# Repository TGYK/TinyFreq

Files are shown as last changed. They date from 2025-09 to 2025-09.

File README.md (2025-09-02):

# TinyFreq
An ATTiny85-based frequency multiplier for use in 1984-1985 Pontiac Fieros for digital cruise control conversion. May be applicable in other use cases. The PCB is designed to be plugged into the harness at C246 where the old cruise control servo control module plugged in, and jumpers relevant stalk signals to back of vehicle via old servo control wires. See table below for details.
|Function|Vacuum Cruise Connector|
|-:|:-|
|Set/Coast|A|
|Multiplied VSS|B|
|GND|C|
|Resume/Acc|D|
|Cruise Enable|E|

## Bill of Materials

|Reference|Device|Value|
|---:|:----:|:----|
|R1|Resistor|100Ω|
|R2|Resistor|10kΩ|
|R3|Resistor|10kΩ|
|R4|Resistor|10kΩ|
|C1|Capacitor|N/A|
|C2|Capacitor|0.33㎌|
|C3|Capacitor|0.1u㎌|
|D1|Diode|1N4001|
|D2|TVS Diode|SA16A|
|D3|TVS Diode|SA30A|
|D4|TVS Diode|SA30A|
|Q1|N-Channel Enhancement FET|2N7000|
|Q2|N-Channel Enhancement FET|2N7000|
|U1|Linear Voltage Regulator|L78L05|
|U2|Microcontroller|ATTiny85|
|J2|Pin Header|2x3, 2.54mm|

## Uploading
### Using an Arduino Uno/Mega as a a programmer.
**THESE STEPS ARE CURRENTLY UNTESTED - FOLLOW AT YOUR OWN RISK**
1. [Setup your Arduino as a programmer and wire to the ISP connection](https://docs.arduino.cc/built-in-examples/arduino-isp/ArduinoISP/), but do not attempt to burn a bootloader to the target.
2. Open the PlatformIO project in VSCode and verify the project builds by clicking the checkmark on the toolbar at the bottom left of the window.
3. Modify the line ```upload_port = SERIAL_PORT_HERE``` within platformio.ini to reflect the serial port that your arduino-as-programmer is connected to, and save the file.
4. If using an arduino mega, modify the line ```${platformio.packages_dir}/tool-avrdude/avrdude.conf``` within platformio.ini to be ```${platformio.packages_dir}/tool-avrdude-megaavr/avrdude.conf``` and save the file.
4. Select the "program_via_ArduinoISP" environment on the bottom toolbar
5. Click the "Upload" arrow on the bottom toolbar

# THIS PROJECT WAS PROUDLY MADE WITHOUT THE USE OF "AI" OR LLM CHATBOTS.

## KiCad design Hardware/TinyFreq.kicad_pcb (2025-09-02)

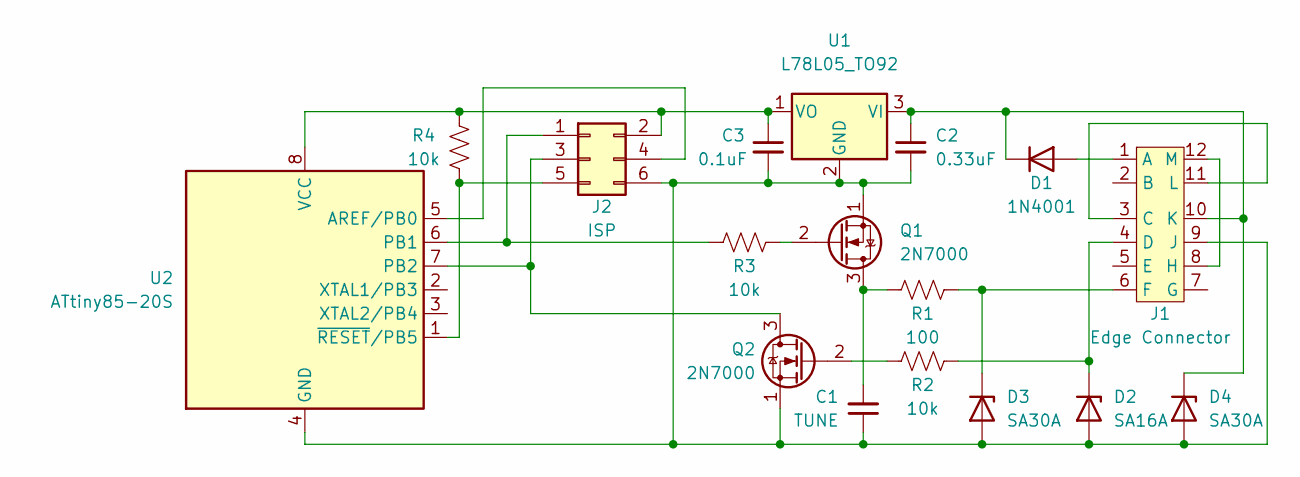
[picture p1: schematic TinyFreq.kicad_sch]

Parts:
C1: TUNE; C_Axial_L3.8mm_D2.6mm_P7.50mm_Horizontal
C2: 0.33uF; C_Axial_L3.8mm_D2.6mm_P7.50mm_Horizontal
C3: 0.1uF; C_Axial_L3.8mm_D2.6mm_P7.50mm_Horizontal
D1: 1N4001; D_DO-41_SOD81_P10.16mm_Horizontal
D2: SA16A; D_A-405_P7.62mm_Horizontal
D3, D4: SA30A; D_A-405_P7.62mm_Horizontal
J1: Edge Connector; CRUISE_EDGE
J2: ISP; PinHeader_2x03_P2.54mm_Vertical
Q1, Q2: 2N7000; TO-92_Inline
R1: 100; R_Axial_DIN0204_L3.6mm_D1.6mm_P5.08mm_Horizontal
R2, R3, R4: 10k; R_Axial_DIN0204_L3.6mm_D1.6mm_P5.08mm_Horizontal
U1: L78L05_TO92; TO-92_Inline
U2: ATtiny85-20S; DIP-8_W7.62mm

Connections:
unnamed: C1.1, C2.2, C3.2, D2.2 (A), D3.2 (A), D4.2 (A), J1.9 (J), J2.6, Q1.1 (S), Q2.1 (S), U1.2 (GND), U2.4 (GND)
unnamed: C1.2, Q1.3 (D), R1.1
unnamed: C2.1, D1.1 (K), D4.1 (K), J1.10 (K), U1.3 (VI)
unnamed: C3.1, J2.2, R4.2, U1.1 (VO), U2.8 (VCC)
unnamed: D1.2 (A), J1.1 (A)
unnamed: D2.1 (K), J1.4 (D), R2.2
unnamed: D3.1 (K), J1.6 (F), R1.2
unnamed: J1.3 (C), J1.11 (L)
unnamed: J1.8 (H), J1.12 (M)
unnamed: J2.1, R3.2, U2.6 (PB1)
unnamed: J2.3, Q2.3 (D), U2.7 (PB2)
unnamed: J2.4, U2.5 (AREF/PB0)
unnamed: J2.5, R4.1, U2.1 (~RESET/PB5)
unnamed: Q1.2 (G), R3.1
unnamed: Q2.2 (G), R2.1

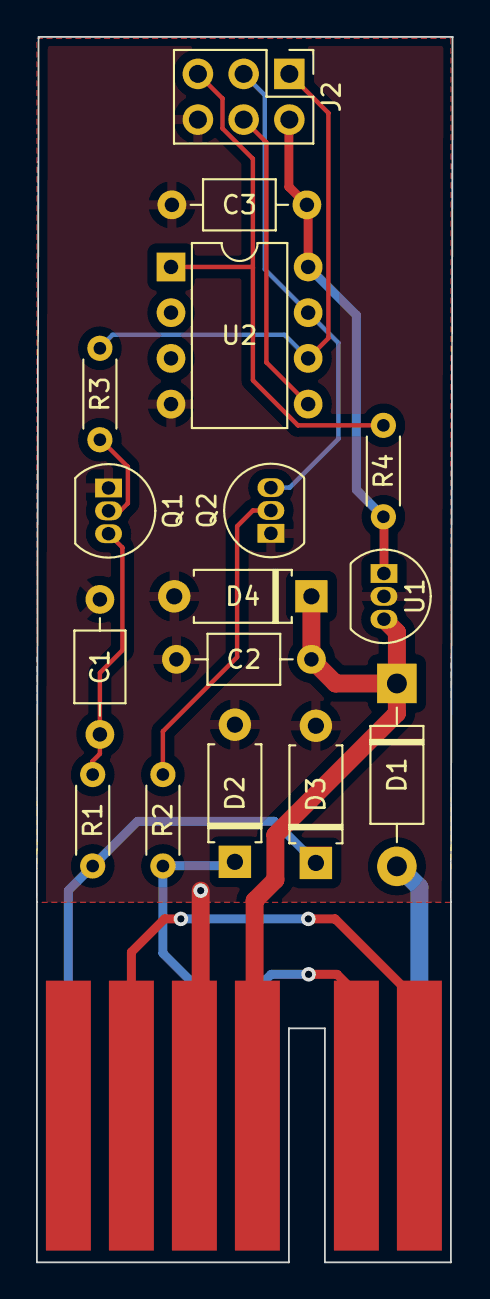
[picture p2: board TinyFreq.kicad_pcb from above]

Board: 2 copper layers, 23.1 x 68.1 mm, 17 parts (0 on the bottom side), 15 nets.

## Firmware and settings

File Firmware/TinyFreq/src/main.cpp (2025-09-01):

#include <Arduino.h>

#define T1_RST TCNT1 &= 0x00
#define T1_STP TCCR1 &= ~((1<<CS10) | (1<<CS11) | (1<<CS12) | (1<<CS13))
#define T1_STA TCCR1 |= ((1<<CS10) | (1<<CS13))
#define T0_RST TCNT0 &= 0x00
#define T0_STP TCCR0B &= ~((1<<CS00) | (1<<CS01) | (1<<CS02))
#define T0_STA TCCR0B |= (1<<CS02)
#define INT0_DS GIMSK &= ~(1<<INT0)
#define INT0_EN GIMSK |= (1<<INT0)

#define FREQ_MULT 2

volatile bool OVF_OCCURRED = true;

ISR(INT0_vect){ //Rising input edge detected
  //Service timer 1 and watchdog, get timer 1 running again ASAP
  T1_STP; //Stop T1 counter
  asm("WDR"); //Reset watchdog timer
  volatile uint8_t togglePW = TCNT1 / (FREQ_MULT * 2); //Read T1 counter, calculate new half PW.. Calculation step may need to be seperate if it takes too long 
  T1_RST; //Reset T1 counter
  T1_STA; //Restart T1 counter

  //OVF flag check - Make sure to measure a full rise-to-rise pulse and not the remainder following a T1 overflow, or a half-pulse during startup.
  if(OVF_OCCURRED){ //If starting up or T1 overflow happened, discard current count/sync
    OVF_OCCURRED = false; //Reset flag
    return; //End interrupt
  }

  //Edge-case - If timer is close to compare match, or is past the new compare match value, trigger an early compare match to toggle output and start a new pulse
  if(TCNT0 > (togglePW - 5)){ //If currently-running putput timer is close to new qpw val or above it, toggle pulse early/sync
    T0_RST; //Reset output timer
    TCCR0B |= (1<<FOC0A); //Force toggle. Bit self-resets? Datasheet ambiguous - FOC0A is a "Strobe bit"
  }

  //Set new compare match for output timer
  OCR0B = togglePW; //Set new half-pulsewidth
  T0_STA; //Start output timer if not already running
  return; //End interrupt
}

ISR(TIM1_OVF_vect){ //Input pulse length overflow
  INT0_DS; //Disable input interrupt
  asm("WDR"); //Reset watchdog timer
  T0_STP; //Stop output timer
  OVF_OCCURRED = true; //Set OVF flag
  T0_RST; //Reset output timer
  PORTB &= ~(1<<PORTB1); //Set output low
  INT0_EN; //Enable input interrupt
  return; //End interrupt
}

void setup() {
  cli(); //Disable global interrupts during setup
  
  //Setup clock
  CLKPR = (CLKPR | (1<<CLKPCE)) & ~((1<<CLKPS3) | (1<<CLKPS2) | (1<<CLKPS1) | (1<<CLKPS0)); //Enable prescaler change
  CLKPR = (CLKPR | (1<<CLKPS3)) & ~(1<<CLKPCE); // clock prescaler = /256
  
  //Setup watchdog 
  WDTCR |= ((1<<WDCE) | (1<<WDE) | (1<<WDP3) | (1<<WDP0)); //Enable watchdog, 8s timeout

  //Setup timers
  TCCR0A |= ((1<<COM0B0) | (1<<WGM01)); //Toggle OC0B0 on match, CTC/mode2
  TIMSK |= (1<<TOIE1); //Overflow int enable on Timer 1

  //Setup DDRB/PORTB
  DDRB = (DDRB | (1<<DDB1)) & ~((1<<DDB0) | (1<<DDB2) | (1<<DDB3) | (1<<DDB4) | (1<<DDB5)); //Unused pins PB0,PB3-5 input for pull-up/high state per datasheet, PB2 input for int0, PB1 output for OC0B0
  PORTB = (PORTB | (1<<PORTB0) | (1<<PORTB2) | (1<<PORTB3) | (1<<PORTB4) | (1<<PORTB5)) & ~(1<<PORTB1); //Pull-up enable, PB1 low

  //Setup interrupts
  MCUCR |= (1<<ISC00) | (1<<ISC01); //INT0 on rising edge
  INT0_EN; //Enable INT0 

  //Setup sleep mode
  MCUCR &= ~((1<<SM0) | (1<<SM1)); //Idle mode
  MCUCR |= (1<<SE); //Enable sleep

  //Setup power-reduction
  ACSR |= (1<<ACD); //Disable analog comparator
  ADCSRA &= ~(1<<ADEN); //Disable ADC
  PRR |= ((1<<PRUSI) | (1<<PRADC)); //Disable USI and ADC clocks

  sei(); //Enable global interrupts
}

void loop() {
  asm("SLEEP"); //Enter idle sleep/wait for interrupt - May be detrimental due to wakeup time (4 cycles + SUT fuse setting)
}

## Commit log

2025-08-31 Initial commit - Schematics, PCB, Code
    [TinyFreq.kicad_pcb, TinyFreq.kicad_sch]
2025-09-01 Interrupt cleanup and operation prioritization, clearer commentson logic.
2025-09-01 Update schematic datasheets and symbols for TVS diodes, update PCB footprints to reflect the pin change.
    [TinyFreq.kicad_pcb, TinyFreq.kicad_sch]
2025-09-01 Generated gerberfiles, updated readme.
    [TinyFreq-B_Cu.gbr, TinyFreq-B_Mask.gbr, TinyFreq-B_Paste.gbr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]
2025-09-02 Updated Schematic/PCB Reference values, update readme, zip gerbers.
    [TinyFreq.kicad_pcb, TinyFreq.kicad_sch]
2025-09-02 Update gerbers to reflect previous reference changes
    [TinyFreq-B_Cu.gbr, TinyFreq-B_Mask.gbr, TinyFreq-B_Paste.gbr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]
